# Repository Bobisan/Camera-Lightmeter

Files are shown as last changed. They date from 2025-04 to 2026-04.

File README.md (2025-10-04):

# Camera Light Meter
Светломер за фотоапарати, който измерва количеството светлина на околната среда, определя правилната експозиция за снимките и пресмята стойностите на настройките, нужни за нея. Вмомента функцоионално работи, но е на breadboard, има неудобни контроли, работи само сързан към захранване и има неоптимизиран код, който води до проблеми. Целта ни е да намалим цялостният размер на проекта и да увеличим неговата надеждност, като го направим на печатна платка и му 3D принтираме корпус, да подобрим и сменим някои от използваните компоненти, като екрана, който смятаме да сменим с някой по-малък и с по-висока резолюция, и бутоните, които смятаме да сменим с ротационни енкодери за по-компактен и удобен дизайн, и смятаме да го направим да работи на презареждаема батерия.

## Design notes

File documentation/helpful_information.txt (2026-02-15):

https://electronics.stackexchange.com/questions/701864/selecting-a-diode-to-prevent-backfeeding-from-5-v-to-usb-c-port

"The 5V rail is only feeding the 3.3V regulator that has a low dropout of about 1V, and the neopixels which work down to 3.7V. Any silicon diode rated for 1000mA minimum will do the job. A 1N4001 (SMD variant is called M1) will do the job just fine, as will do any higher diode in the 1N4001/M1 series, up to 7, i.e. up to 1N4007 or M7. The lower the number, the lower the reverse voltage rating, but all of them are much higher than your application requires, so 1N4001 or M1 will be perfect."

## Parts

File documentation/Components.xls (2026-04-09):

Part | Link | €€
ESP 32 S3-N16R8 devboard | https://www.aliexpress.com/item/1005006418608267.html | 6.91 €
TP4056 5V 1ALithium Battery Charging Module | https://www.aliexpress.com/item/1005007593596607.html | 1.29 €
5x VEML7700 Ambient Light Sensor Module | https://www.aliexpress.com/item/1005008125338381.html | 7.56 €
5x 3V3 Buck Converter | https://www.aliexpress.com/item/1005006308573192.html | 3.08 €
0.91 inch OLED I2C Module | https://www.aliexpress.com/item/1005007141250330.html | 1.95 €
3.7V 1200mAh Polymer Lithium Rechargeable Battery | https://www.aliexpress.com/item/1005007997457057.html | 4.74 €
9-12V Linear Solenoid | https://www.aliexpress.com/item/1005009148817721.html | 3.12 €
5x 9V 1.3A Step Up Power Module | https://www.aliexpress.com/item/1005008051438437.html | 5.17 €
10x 16 pin USB C port | https://www.aliexpress.com/item/1005009438498535.html?curPageLogUid=dABlVYe4r3X1 | 1.79 €
5V to 3.3V converter | https://store.comet.bg/en/Catalogue/Product/15486/ | 0.85 €
CH340N ESP Programmer | https://www.aliexpress.com/item/1005010667337655.html | 1.46 €
0.1uF Capacitor x 100 | https://store.comet.bg/en/Catalogue/Product/16789/ | 0.38 €
1uF Capacitor x 10 | https://store.comet.bg/en/Catalogue/Product/6645/ | 0.10 €
4.7uF Capacitor x 10 | https://store.comet.bg/en/Catalogue/Product/16600/ | 0.43 €
10uF Capacitor x 10 | https://store.comet.bg/en/Catalogue/Product/44616/ | 0.15 €
JST connectors | https://elimex.bg/product/96841-komplekt-saedinitel-jst-xh2-54-maji-i-jenski-230-br | 5.06 €
10k Resistor x 20 | https://store.comet.bg/en/Catalogue/Product/29760/ | 0.64 €
Fuses x 5 | https://store.comet.bg/en/Catalogue/Product/7765/ | 1.80 €
6mm boot button x 10 | https://store.comet.bg/en/Catalogue/Product/24679/ | 0.99 €
Vertical shutter push button x 10 | https://store.comet.bg/en/Catalogue/Product/4087/ | 0.81 €
FDV305N MOSFET for Solanoid control x 4 | https://store.comet.bg/en/Catalogue/Product/46042/ | 0.40 €
FZT849 BJT for Solanoid Control x 4 | https://store.comet.bg/en/Catalogue/Product/9718/ | 1.64 €
TS4148-0805 diode for solanoid control x 4 | https://store.comet.bg/en/Catalogue/Product/18153/ | 0.17 €
1.1k Resistor x 10 | https://store.comet.bg/en/Catalogue/Product/3528/ | 0.17 €
22k Resistor x 10 | https://store.comet.bg/en/Catalogue/Product/4213/ | 0.17 €
ESP 32 S3-N8R8 chip x 3 | https://store.comet.bg/en/Catalogue/Product/41974/ | 12.91 €

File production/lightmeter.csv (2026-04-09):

Reference | Qty | Value | DNP | Exclude from BOM | Exclude from Board | Footprint | Datasheet
C1 | 1 | 4.7u |  |  |  | Capacitor_SMD:C_0805_2012Metric | ~
C2,C3,C5,C8,C9 | 5 | 0.1u |  |  |  | Capacitor_SMD:C_0805_2012Metric | ~
C4 | 1 | 1u |  |  |  | Capacitor_SMD:C_0805_2012Metric | ~
C6 | 1 | 10uF/25V(20%) |  |  |  | Capacitor_SMD:C_0805_2012Metric | ~
C7 | 1 | 1uF/16V(10%) |  |  |  | Capacitor_SMD:C_0805_2012Metric | ~
C10 | 1 | 0.1uF/50V(10%) |  |  |  | Capacitor_SMD:C_0805_2012Metric | ~
D1 | 1 | TS4148 |  |  |  | Diode_SMD:D_0805_2012Metric | ~
J1 | 1 | 5V input |  |  |  | Connector_JST:JST_EH_B2B-EH-A_1x02_P2.50mm_Vertical | ~
J2 | 1 | programmer |  |  |  | Connector_JST:JST_EH_B5B-EH-A_1x05_P2.50mm_Vertical | ~
J4 | 1 | VEML7700 |  |  |  | Connector_PinHeader_2.54mm:PinHeader_1x05_P2.54mm_Vertical | ~
J6 | 1 | OLED Display |  |  |  | Connector_JST:JST_EH_B4B-EH-A_1x04_P2.50mm_Vertical | ~
J7 | 1 | Solanoid |  |  |  | Connector_JST:JST_EH_B2B-EH-A_1x02_P2.50mm_Vertical | ~
Q1 | 1 | FDV305N |  |  |  | Package_TO_SOT_SMD:SOT-23 | http://www.diodes.com/assets/Datasheets/ds30366.pdf
R1,R2,R3,R4,R5,R6,R8,R9,R11,R12,R13,R16 | 12 | 10k |  |  |  | Resistor_SMD:R_0805_2012Metric | ~
R7 | 1 | 10K(1%) |  |  |  | Resistor_SMD:R_0805_2012Metric | ~
R10 | 1 | Fuse |  |  |  | Fuse:Fuse_1206_3216Metric | ~
R14 | 1 | 1.1K |  |  |  | Resistor_SMD:R_0805_2012Metric | ~
R15 | 1 | 22K |  |  |  | Resistor_SMD:R_0805_2012Metric | ~
SW1 | 1 | Shutter |  |  |  | Vertical_Push_Button:Vertical_Push_Button | ~
SW2 | 1 | Value Rot |  |  |  | Rotary_JST:Rotary_JST | ~
SW3 | 1 | BOOT |  |  |  | Button_Switch_THT:SW_PUSH_1P1T_6x3.5mm_H4.3_APEM_MJTP1243 | ~
SW4 | 1 | Setting Rot |  |  |  | Rotary_JST:Rotary_JST | ~
U1 | 1 | NCP1117-3.3_SOT223 |  |  |  | Package_TO_SOT_SMD:SOT-223-3_TabPin2 | http://www.onsemi.com/pub_link/Collateral/NCP1117-D.PDF
U2 | 1 | ESP32-S3-WROOM-1 |  |  |  | RF_Module:ESP32-S3-WROOM-1 | https://www.espressif.com/sites/default/files/documentation/esp32-s3-wroom-1_wroom-1u_datasheet_en.pdf
U3 | 1 | FZT849 |  |  |  | Package_TO_SOT_SMD:SOT-223-3_TabPin2 | https://www.analog.com/media/en/technical-documentation/data-sheets/112935ff.pdf
U4 | 1 | ~ |  |  |  | Boost_Converter_Module_Footprint:Boost_Converter_Module

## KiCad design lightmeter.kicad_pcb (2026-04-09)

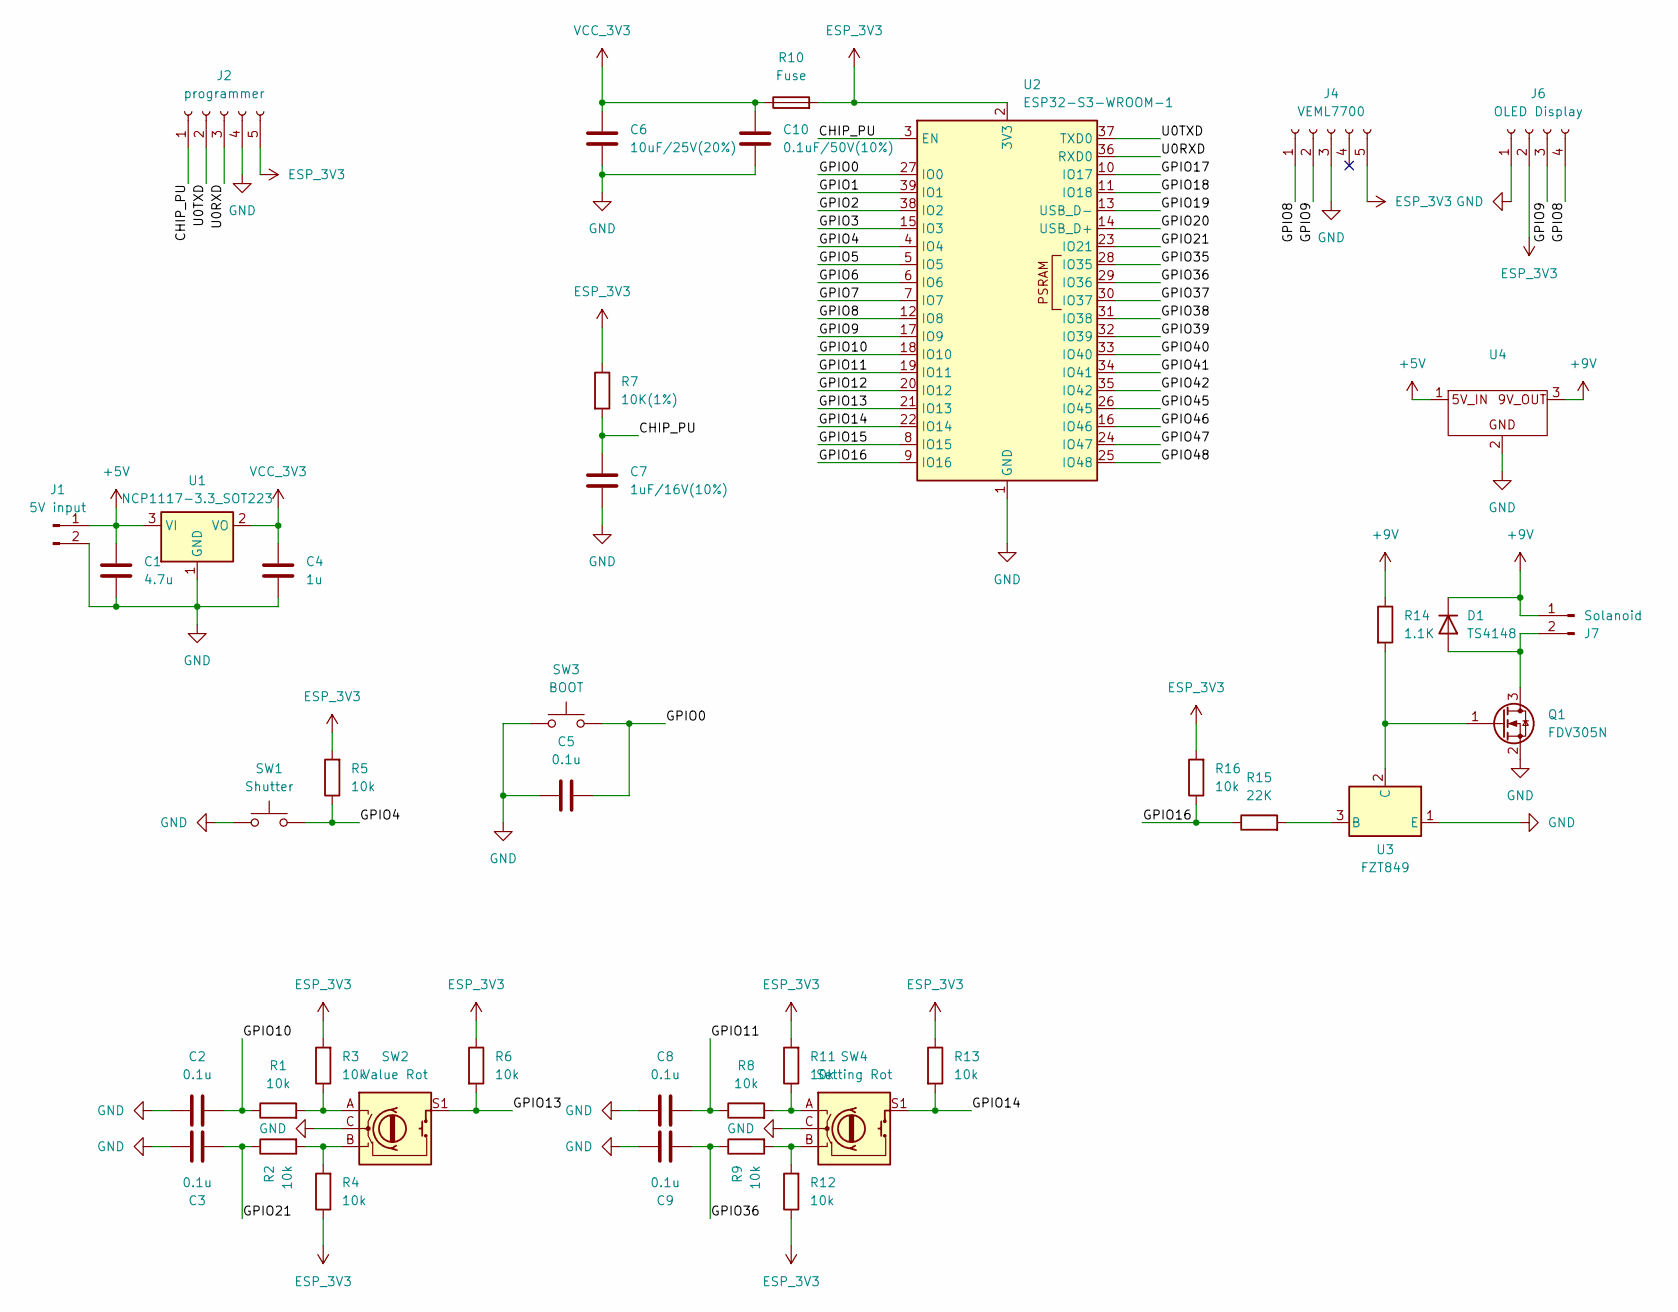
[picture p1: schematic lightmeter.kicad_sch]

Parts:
C1: 4.7u; C_0805_2012Metric
C2, C3, C5, C8, C9: 0.1u; C_0805_2012Metric
C4: 1u; C_0805_2012Metric
C6: 10uF/25V(20%); C_0805_2012Metric
C7: 1uF/16V(10%); C_0805_2012Metric
C10: 0.1uF/50V(10%); C_0805_2012Metric
D1: TS4148; D_0805_2012Metric
J1: 5V input; JST_EH_B2B-EH-A_1x02_P2.50mm_Vertical
J2: programmer; JST_EH_B5B-EH-A_1x05_P2.50mm_Vertical
J4: VEML7700; PinHeader_1x05_P2.54mm_Vertical
J6: OLED Display; JST_EH_B4B-EH-A_1x04_P2.50mm_Vertical
J7: Solanoid; JST_EH_B2B-EH-A_1x02_P2.50mm_Vertical
Q1: FDV305N; SOT-23
R1, R2, R3, R4, R5, R6, R8, R9, R11, R12, R13, R16: 10k; R_0805_2012Metric
R7: 10K(1%); R_0805_2012Metric
R10: Fuse; Fuse_1206_3216Metric
R14: 1.1K; R_0805_2012Metric
R15: 22K; R_0805_2012Metric
SW1: Shutter; Vertical_Push_Button
SW2: Value Rot; Rotary_JST
SW3: BOOT; SW_PUSH_1P1T_6x3.5mm_H4.3_APEM_MJTP1243
SW4: Setting Rot; Rotary_JST
U1: NCP1117-3.3_SOT223; SOT-223-3_TabPin2
U2: ESP32-S3-WROOM-1
U3: FZT849; SOT-223-3_TabPin2
U4: Boost_Converter_Module

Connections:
+5V: C1.1, J1.1, U1.3 (VI), U4.1
+9V: D1.1 (K), J7.1, R14.1, U4.3
/CHIP_PU: C7.1, J2.1, R7.2, U2.3 (EN)
/GPIO0: C5.2, SW3.2, U2.27 (IO0)
/GPIO1: U2.39 (IO1)
/GPIO2: U2.38 (IO2)
/GPIO3: U2.15 (IO3)
/GPIO4: R5.1, SW1.2, U2.4 (IO4)
/GPIO5: U2.5 (IO5)
/GPIO6: U2.6 (IO6)
/GPIO7: U2.7 (IO7)
/GPIO8: J4.1, J6.4, U2.12 (IO8)
/GPIO9: J4.2, J6.3, U2.17 (IO9)
/GPIO10: C2.2, R1.1, U2.18 (IO10)
/GPIO11: C8.2, R8.1, U2.19 (IO11)
/GPIO12: U2.20 (IO12)
/GPIO13: R6.2, SW2.S1, U2.21 (IO13)
/GPIO14: R13.2, SW4.S1, U2.22 (IO14)
/GPIO15: U2.8 (IO15)
/GPIO16: R15.1, R16.1, U2.9 (IO16)
/GPIO17: U2.10 (IO17)
/GPIO18: U2.11 (IO18)
/GPIO19: U2.13 (USB_D-)
/GPIO20: U2.14 (USB_D+)
/GPIO21: C3.2, R2.1, U2.23 (IO21)
/GPIO35: U2.28 (IO35)
/GPIO36: C9.2, R9.1, U2.29 (IO36)
/GPIO37: U2.30 (IO37)
/GPIO38: U2.31 (IO38)
/GPIO39: U2.32 (IO39)
/GPIO40: U2.33 (IO40)
/GPIO41: U2.34 (IO41)
/GPIO42: U2.35 (IO42)
/GPIO45: U2.26 (IO45)
/GPIO46: U2.16 (IO46)
/GPIO47: U2.24 (IO47)
/GPIO48: U2.25 (IO48)
/U0RXD: J2.3, U2.36 (RXD0)
/U0TXD: J2.2, U2.37 (TXD0)
ESP_3V3: J2.5, J4.5, J6.2, R3.2, R4.1, R5.2, R6.1, R7.1, R10.2, R11.2, R12.1, R13.1, R16.2, U2.2 (3V3)
GND: C1.2, C2.1, C3.1, C4.2, C5.1, C6.2, C7.2, C8.1, C9.1, C10.2, J1.2, J2.4, J4.3, J6.1, Q1.2 (S), SW1.1, SW2.C, SW3.1, SW4.C, U1.1 (GND), U2.1 (GND), U2.40 (GND), U2.41 (GND), U3.1 (E), U4.2
unnamed: D1.2 (A), J7.2, Q1.3 (D)
unnamed: Q1.1 (G), R14.2, U3.2 (C)
unnamed: R1.2, R3.1, SW2.A
unnamed: R2.2, R4.2, SW2.B
unnamed: R8.2, R11.1, SW4.A
unnamed: R9.2, R12.2, SW4.B
unnamed: R15.2, U3.3 (B)
VCC_3V3: C4.1, C6.1, C10.1, R10.1, U1.2 (VO)

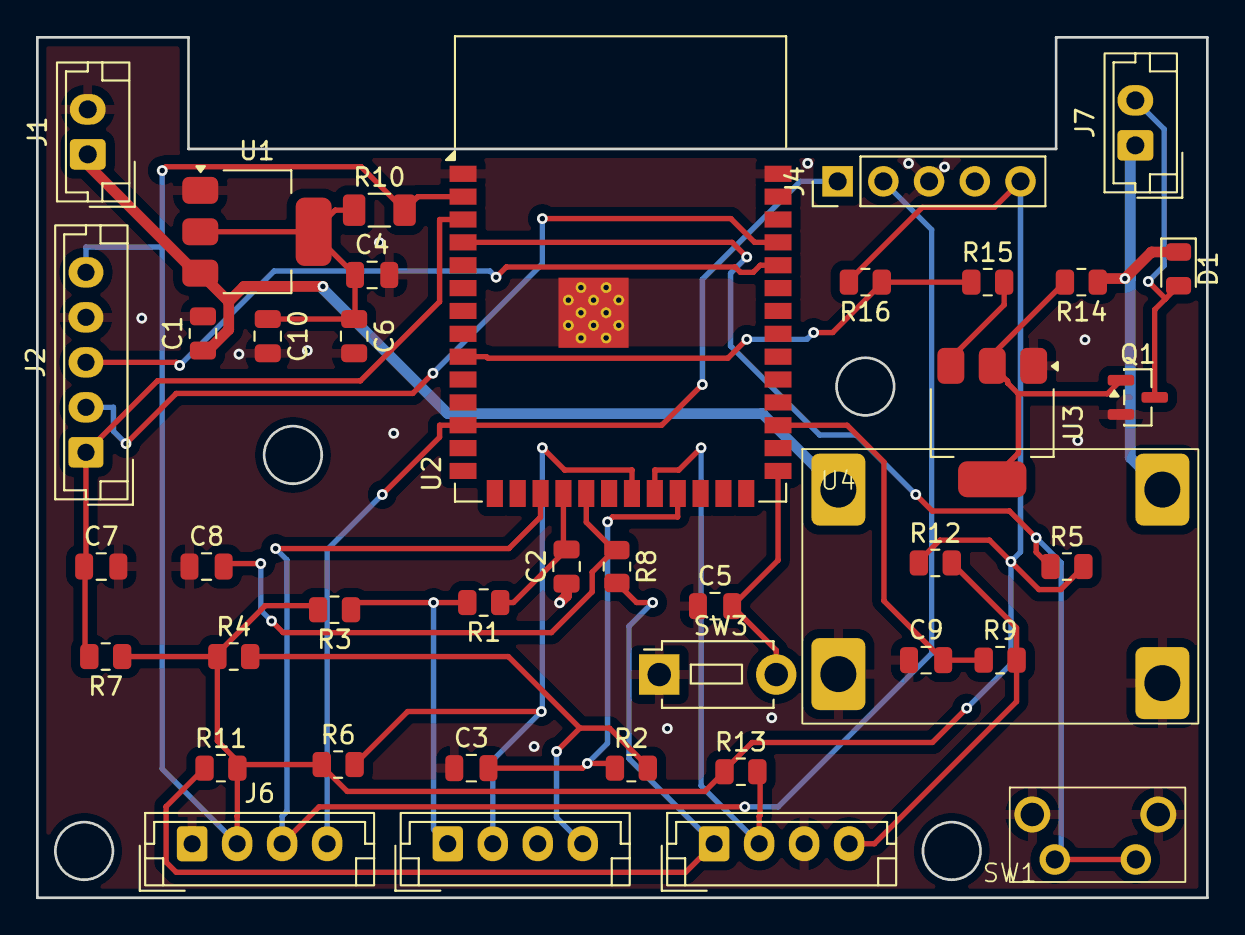
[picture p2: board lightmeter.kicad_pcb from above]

Board: 2 copper layers, 65.0 x 47.8 mm, 41 parts (0 on the bottom side), 26 nets.

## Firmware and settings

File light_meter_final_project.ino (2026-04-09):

#include <SPI.h>
#include <Wire.h>
#include <Adafruit_GFX.h>
#include <Adafruit_SSD1306.h>
//#include <SparkFun_VEML7700_Arduino_Library.h>
#include <Adafruit_VEML7700.h>
#include <math.h>

#define SCREEN_WIDTH 128
#define SCREEN_HEIGHT 32
#define OLED_RESET    -1
#define ISO_BUTTON    13
#define RE1a 10
#define RE1b 21
#define RE2a 11
#define RE2b 36

Adafruit_SSD1306 display(SCREEN_WIDTH, SCREEN_HEIGHT, &Wire, OLED_RESET);
//VEML7700 veml;
Adafruit_VEML7700 veml = Adafruit_VEML7700();

// ── Lookup tables ──────────────────────────────────────────────────────────────
const float arr_full_seconds_SP[]  = {30,25,20,15,13,10,8,6,5,4,3,2.5,2,1.6,1.3,1};
const float arr_parts_seconds_SP[] = {1.3,1.6,2,2.5,3,4,5,6,8,10,13,16,20,25,30,40,50,60,80,100,125,160,200,250,320,400,500,640,800,1000,1250,1600,2000,2500,3200,4000};
const float arr_Aperture[] = {1,1.1,1.2,1.4,1.6,1.8,2,2.2,2.4,2.8,3.2,3.5,4,4.5,5,5.6,6.3,7.1,8,9,10,11,13,14,16,18,20,22,25,29};

#define FULL_SP_COUNT   16
#define PARTS_SP_COUNT  36
#define TOTAL_SP_COUNT  (FULL_SP_COUNT + PARTS_SP_COUNT)  // 52
#define MAX_AP_INDEX    29

// ── State ──────────────────────────────────────────────────────────────────────
volatile int  enc1Delta  = 0;   // RE1: aperture / ISO adjust
volatile int  enc2Delta  = 0;   // RE2: select parameter
volatile uint8_t enc1Last = 0;
volatile uint8_t enc2Last = 0;

int  current_position = 0;      // 0 = aperture, 1 = shutter
int  DisplayVariant = 0;      // 0 = main, 1 = ISO
float  ISO = 100;
int  Aperature_Index = 9;
int  SP_Index = 32;
float SP_value = 60;
float lux = 0;
float Aperature_Value = 2.8;
float ev = 0;

bool  needsUpdate= true;
unsigned long startTimer= 0;
const unsigned long HOLD_DURATION = 10000;  // ms to hold RE1 before exiting ISO screen

// ── Quadrature ISR helper ──────────────────────────────────────────────────────
// Full-step table: only counts on clean AB transitions to reduce bounce.
static const int8_t QEM[16] = {
  0,-1, 1, 0,
  1, 0, 0,-1,
  -1, 0, 0, 1,
  0, 1,-1, 0
};

void IRAM_ATTR isr_enc1() {
  uint8_t cur = (digitalRead(RE1a) << 1) | digitalRead(RE1b);
  enc1Delta += QEM[(enc1Last << 2) | cur];
  enc1Last   = cur;
}

void IRAM_ATTR isr_enc2() {
  uint8_t cur = (digitalRead(RE2a) << 1) | digitalRead(RE2b);
  enc2Delta += QEM[(enc2Last << 2) | cur];
  enc2Last   = cur;
}

// ── SP helpers ────────────────────────────────────────────────────────────────
float spValueFromIndex(int idx) {
  if (idx < FULL_SP_COUNT)
    return arr_full_seconds_SP[idx];
  return arr_parts_seconds_SP[idx - FULL_SP_COUNT];
}

// ── Apreture helpers ────────────────────────────────────────────────────────────────
int findNearestApertureIndex(float value) {
  int bestIndex = 0;
  float bestDiff = fabs(value - arr_Aperture[0]);

  for (int i = 1; i <= MAX_AP_INDEX; i++) {
    float diff = fabs(value - arr_Aperture[i]);
    if (diff < bestDiff) {
      bestDiff = diff;
      bestIndex = i;
    }
  }
  return bestIndex;
}
// ── Setup ─────────────────────────────────────────────────────────────────────
void setup() {
  Serial.begin(115200);
  Wire.begin(8,9);
  pinMode(RE1a, INPUT);
  pinMode(RE1b, INPUT);
  pinMode(RE2a, INPUT);
  pinMode(RE2b, INPUT);
  pinMode(ISO_BUTTON, INPUT_PULLUP);

  // Seed the "last" state so first edge doesn't produce a phantom step
  enc1Last = (digitalRead(RE1a) << 1) | digitalRead(RE1b);
  enc2Last = (digitalRead(RE2a) << 1) | digitalRead(RE2b);

  // Attach interrupts to both pins of each encoder
  attachInterrupt(digitalPinToInterrupt(RE1a), isr_enc1, CHANGE);
  attachInterrupt(digitalPinToInterrupt(RE1b), isr_enc1, CHANGE);
  attachInterrupt(digitalPinToInterrupt(RE2a), isr_enc2, CHANGE);
  attachInterrupt(digitalPinToInterrupt(RE2b), isr_enc2, CHANGE);

  if (!display.begin(SSD1306_SWITCHCAPVCC, 0x3C)) {
    Serial.println("SSD1306 allocation failed");
    for (;;);
  }
  if (veml.begin() == false)
  {
    Serial.println("Unable to communicate with the VEML7700. Please check the wiring. Freezing...");
    while (1)
        ;
  }
  //veml.setGain(VEML7700_GAIN_1);
  //veml.setIntegrationTime(VEML7700_IT_100MS);

  display.clearDisplay();
  display.display();

  SP_value = spValueFromIndex(SP_Index);
}

// ── Draw OLED (only called when needsUpdate is true) ──────────────────────────
void updateDisplay() {
  display.clearDisplay();
  display.setTextSize(1);
  display.setTextColor(WHITE, BLACK);
  display.setCursor(0, 0);

  if (DisplayVariant == 0) {
    display.printf("AP: f/%.1f\n", Aperature_Value);
    if (SP_Index < FULL_SP_COUNT)
      display.printf("SP: %.1fs\n", SP_value);
    else
      display.printf("SP: 1/%.0f\n", SP_value);
  } else {
    display.println("ISO");
    display.printf("%d\n", ISO);
  }

  display.display();
  needsUpdate = false;
}

// ── Loop ──────────────────────────────────────────────────────────────────────
void loop() {
  lux = veml.readLux();
  ev = log2(lux/2.5);
  Serial.printf("ev:%.1f\n", ev);
  // ── Atomically grab and clear encoder deltas ──────────────────────────────
  noInterrupts();
  int d1 = enc1Delta;  enc1Delta = 0;
  int d2 = enc2Delta;  enc2Delta = 0;
  interrupts();

  // ── RE2: cycle through parameters (aperture / shutter) ───────────────────
  if (d2 != 0 && DisplayVariant == 0) {
    // One detent = one step; clamp to number of selectable params
    current_position = constrain(current_position + (d2 > 0 ? 1 : -1), 0, 1);
    needsUpdate = true;
  }

  // ── RE1: adjust value ─────────────────────────────────────────────────────
  if (d1 != 0) {
    if (DisplayVariant == 0) {
      switch (current_position) {
        case 0:   // Aperture
          Aperature_Index = constrain(Aperature_Index + d1, 0, MAX_AP_INDEX);
          Aperature_Value = arr_Aperture[Aperature_Index];
          SP_value = ((250*Aperature_Value*Aperature_Value)/ISO*lux);
          needsUpdate = true;
          break;
        case 1:   // Shutter speed
          SP_Index = constrain(SP_Index + d1, 0, TOTAL_SP_COUNT - 1);
          SP_value = spValueFromIndex(SP_Index);

          float calculatedAperture = sqrt((lux * ISO * SP_value) / 250.0);

          Aperature_Index  = findNearestApertureIndex(calculatedAperture);
         // Aperature_Value = arr_Aperture[Aperature_Index];
          Aperature_Value = calculatedAperture;
          needsUpdate = true;
          break;
      }
    } else {
      // ISO screen: double/halve per detent
      if (d1 > 0) {
        for (int i = 0; i < abs(d1); i++) ISO = max(ISO * 2, ISO + 1); // guard against overflow
      } else {
        for (int i = 0; i < abs(d1); i++) ISO = max(1.0f, ISO / 2);
      }
      needsUpdate = true;
      startTimer  = 0;  // reset the hold-to-exit timer on any adjustment
    }
  }

  // ── ISO button: enter ISO screen ─────────────────────────────────────────
  // Button is INPUT_PULLUP → active LOW
  if (digitalRead(ISO_BUTTON) == LOW && DisplayVariant == 0) {
    DisplayVariant = 1;
    needsUpdate    = true;
    startTimer     = 0;
  }

  // ── Auto-exit ISO screen after HOLD_DURATION of no encoder activity ───────
  if (DisplayVariant == 1) {
    if (d1 == 0) {
      if (startTimer == 0) startTimer = millis();
      if (millis() - startTimer >= HOLD_DURATION) {
        DisplayVariant = 0;
        needsUpdate = true;
        startTimer = 0;
      }
    } else {
      startTimer = 0;   // activity → reset hold timer
    }
  }

  // ── Render ────────────────────────────────────────────────────────────────
  // Only push to OLED when something changed; this prevents I²C bus saturation.
  if (needsUpdate) {
    updateDisplay();
  }
}

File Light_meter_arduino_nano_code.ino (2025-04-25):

    #include <LCD-I2C.h>
    #include <Wire.h>
    #include <SparkFun_VEML7700_Arduino_Library.h> // Include the SparkFun VEML7700 library
    // buttons : ISO = 9, SP = 10, A = 13, Contrast = 7, plus + 10 = 1, minus -10 = 8
    VEML7700 veml; // Create a VEML7700 object
    float arr_full_seconds_SP[] = { 30, 25, 20, 15, 13, 10, 8, 6, 5, 4, 3, 2.5, 2, 1.6, 1.3, 1};
    float arr_parts_seconds_SP[] = {1.3, 1.6, 2, 2.5, 3, 4, 5, 6, 8, 10, 13, 16, 20, 25, 30, 40, 50, 60, 80, 100, 125, 160, 200, 250, 320, 400, 500, 640, 800, 1000, 1250, 1600, 2000, 2500, 3200, 4000};
    float arr_Apreture[] = {1, 1.1, 1.2, 1.4, 1.6, 1.8, 2, 2.2, 2.4, 2.8, 3.2, 3.5, 4, 4.5, 5, 5.6, 6.3, 7.1, 8, 9, 10, 11, 13, 14, 16, 18, 20, 22, 25, 29};
    int SP_counter = 32;
    int Apreture_counter = 9;
    int Contrast = 130;
    LCD_I2C lcd(0x27, 16, 2); 
    float ISO_value = 100;
    float A_value = 2.8,SP_value = 60;
    int ISO_button = 9, SP_button = 10, A_button = 13, Contrast_button = 7, plus_button = 6, minus_button = 8;
    int ISO_button_state = 0, SP_button_state = 0, A_button_state = 0, Contrast_button_state = 0, plus_button_state = 0, minus_button_state = 0, Last_plus_button_state = 0, Last_minus_button_state = 0;
    int choose_const = -1, change_value = -1, go_back_to_normal = 0, Last_ISO = 0, Last_SP = 0, Last_A = 0, Last_SP_value = 0, Last_ISO_value = 0, Last_A_value = 0, ISO_value_for_calc = 0, Last_ISO_value_for_calc = 0;
    float lux = 0, SP_value_for_calc = 0, Last_SP_value_for_calc = 0, A_value_for_calc = 0, Last_A_value_for_calc = 0;
    void Parameter_menu(){
        lcd.clear();
        lcd.setCursor(0, 0);
        lcd.print("ISO");
        lcd.setCursor(5, 0);
        lcd.print("SP");
        lcd.setCursor(13, 0);
        lcd.print("A");
        lcd.setCursor(0, 1);
        lcd.print(ISO_value, 0);
        if(SP_counter > -1 && SP_counter < 16){
            SP_value = arr_full_seconds_SP[SP_counter];
            lcd.setCursor(5, 1);
            lcd.print(SP_value, 1);
        }
        if(SP_counter > 15 && SP_counter < 53){
            SP_value = arr_parts_seconds_SP[SP_counter - 15];
            lcd.setCursor(4, 1);
            lcd.print("1/");
            lcd.setCursor(6, 1);
            lcd.print(SP_value, 1);
        }
        lcd.setCursor(12, 1);
        lcd.print(A_value);
    }
    void ISO_CHANGE_double() {
        int NewISO = ISO_value*2;
        if(NewISO < 10000){
        ISO_value = NewISO;
        lcd.setCursor(0, 1);
        lcd.print("    ");
        lcd.setCursor(0, 1);
        lcd.print(ISO_value, 0);
        }

    }
    void ISO_CHANGE_decrease(){
        int NewISO = ISO_value*0.5;
        if(NewISO >= 25){
            ISO_value = NewISO;
            lcd.setCursor(0, 1);
            lcd.print("    ");
            lcd.setCursor(0, 1);
            lcd.print(ISO_value, 0);
        }
    }
    int SP_CHANGE(){
        if(SP_counter > -1 && SP_counter <= 52){
            lcd.setCursor(4, 1);
            lcd.print("        ");
            if(SP_counter > -1 && SP_counter < 16){
                SP_value = arr_full_seconds_SP[SP_counter];
                SP_value_for_calc = SP_value;
                lcd.setCursor(5, 1);
                lcd.print(SP_value, 1);
            }
            if(SP_counter > 15 && SP_counter < 53){
                SP_value = arr_parts_seconds_SP[SP_counter - 15];
                SP_value_for_calc = 1/SP_value;
                lcd.setCursor(4, 1);
                lcd.print("1/");
                lcd.setCursor(6, 1);
                lcd.print(SP_value, 1);
            }
        }
    }

    void setup()
    {
        Serial.begin(9600); // Start serial communication
        Wire.begin(); // Begin I2C communication
        analogWrite(6, Contrast);// Set contrast for the LCD
        lcd.begin(&Wire); // Initialize the LCD (16x2)
        lcd.backlight();
        lcd.display();
        lcd.setCursor(0, 0);
        lcd.print("Choose parameter:");
        lcd.setCursor(2, 1);
        lcd.print("ISO");
        lcd.setCursor(7, 1);
        lcd.print("SP");
        lcd.setCursor(13, 1);
        lcd.print("A");
        //lcd.blink();
        pinMode(ISO_button, INPUT);
        pinMode(SP_button, INPUT);
        pinMode(A_button, INPUT);
        pinMode(Contrast_button, INPUT);
        pinMode(plus_button, INPUT);
        pinMode(minus_button, INPUT);
        // Initialize the VEML7700 sensor
        if (veml.begin() == false)
        {
            Serial.println("Unable to communicate with the VEML7700. Please check the wiring. Freezing...");
            while (1)
                ;
        }
    }
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

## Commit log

2026-02-15 Commiting all schematic and pcb files
    [Components.xls, lightmeter.kicad_pcb, lightmeter.kicad_sch]
2026-03-02 Add files via upload
    code progress. Need to read about shrift changes in size and all that other than that prototype rotter encoders should work
2026-03-09 Commiting new branch
    [Components.xls]
2026-03-09 Added power supply block to the schematic
    [lightmeter.kicad_sch]
2026-03-22 Added the Rotary encoders and the push buttons, that are going to be used, in the schematic.
    [lightmeter.kicad_sch]
2026-03-23 Finished schematic. Layout is next
    [Components.xls, lightmeter.kicad_sch]
2026-03-24 Replaced the usb C port with a connector for a programmer module
    [lightmeter.kicad_sch]
2026-03-24 Annotated the schematic
    [lightmeter.kicad_sch]
2026-03-31 Assigned footprints to all components
    [Components.xls, lightmeter.kicad_pcb, lightmeter.kicad_sch]
2026-04-03 Fixed the solanoid control part of the schematic as well as the connector for the VEML7700 light sensor, now I am really ready to start the layout proccess
    [Components.xls, lightmeter.kicad_pcb, lightmeter.kicad_sch]
2026-04-03 Fixed a few wrong footprints
    [Components.xls, lightmeter.kicad_pcb, lightmeter.kicad_sch]
2026-04-04 ixed even more issues with the footprints, configured placement and ran autorouter. Still have settings to adjust though.
    [lightmeter.kicad_pcb, lightmeter.kicad_sch]
2026-04-05 Finished PCB. I will review it one more time and send it for fabrication.
    [lightmeter.kicad_pcb]
2026-04-09 Finished board and exported production files
    [Components.xls, designators.csv, lightmeter.csv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]
